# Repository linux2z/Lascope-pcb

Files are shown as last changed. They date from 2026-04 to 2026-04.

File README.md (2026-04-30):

# <div align="center">🧬 Lascope Hardware Ecosystem</div>

<div align="center">
  
  
  
</div>

<br />

<div align="center">
  <p><b>High-performance, hardware-accelerated imaging platform for next-generation endoscopy.</b></p>
  <i>Precision-engineered PCB designs for medical-grade reliability and low-latency throughput.</i>
</div>

---

## 📸 Hardware Overview: CM3588 Plus
The core of the Lascope system is the **FriendlyElec CM3588 Plus**, a high-performance SoM (System on Module) powered by the Rockchip RK3588.

<div align="center">
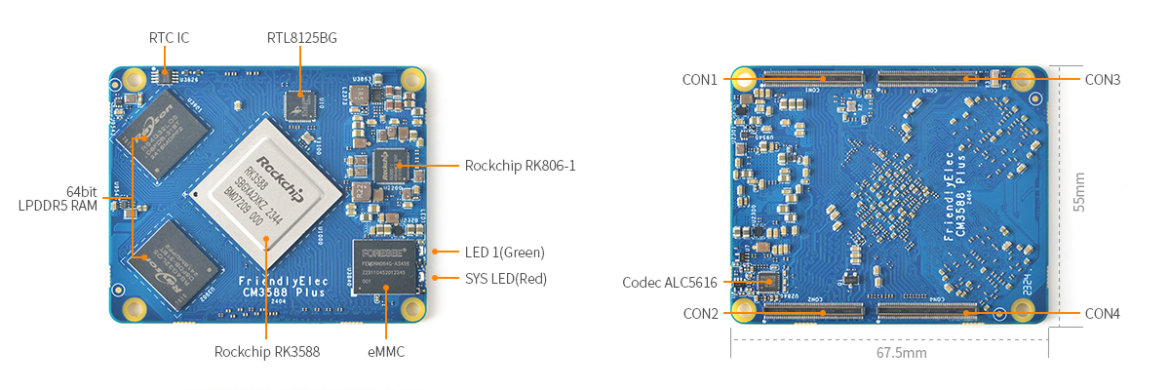
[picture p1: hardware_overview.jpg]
CM3588 Plus Hardware Layout
  
  <br />
  <i>Fig 1.0: CM3588 Plus Component Mapping (RK3588, LPDDR5 RAM, eMMC, and Peripherals)</i>
</div>

---

## 💎 Design Philosophy
The Lascope hardware architecture is built on a **Modular Sub-PCB Model**. By separating the high-speed computing core from the user interface and illumination modules, we ensure:
- **EMC Isolation:** High-speed signals are isolated on the Main Board (Board 1).
- **Serviceability:** Individual modules (Buttons, LEDs, Battery) can be replaced or upgraded independently.
- **Thermal Efficiency:** Optimized heat dissipation paths for the RK3588 SoC.

---

## 📂 Modular Deliverables

### 🖥️ Core Processing Unit
| Board ID | Name | Role | Specs |
| :--- | :--- | :--- | :--- |
| **BOARD 1** | **Main Controller** | System Logic & Vision | RK3588, 64-bit LPDDR5, Dual RTL8125BG |

### 💡 Illumination & Sensors
| Board ID | Name | Role | Key Specs |
| :--- | :--- | :--- | :--- |
| **BOARD 5** | **Camera LED** | Endoscopic Light Source | High-CRI 5700K LEDs |
| **BOARD 6** | **LED Controller** | PWM Dimming Logic | TLC59108 I2C Driver |

### 🔋 Power & Control
| Board ID | Name | Role | Key Specs |
| :--- | :--- | :--- | :--- |
| **BOARD 4** | **Battery BMS** | Power Management | Smart Charging & Fuel Gauge |
| **BOARD 2** | **Button Sub-PCB** | Tactile Interface | 5-Way Navigation Switch |
| **BOARD 3** | **Status Panel** | Visual Feedback | 5-LED Diagnostic Array |
| **BOARD 7** | **Power Logic** | Soft-Start Circuitry | Latching Power Switch |

---

## 🛠️ Production Standards

| Attribute | Specification |
| :--- | :--- |
| **PCB Stackup** | 8-Layer High-Density (Main) / 2-Layer (Sub) |
| **Material** | Isola 370HR / IT-180A (High TG) |
| **Surface Finish** | Lead-Free ENIG (Au: 0.05um, Ni: 3um) |
| **Impedance** | 90Ω Differential (USB), 100Ω (Ethernet) |
| **Certification** | IPC-A-600 Class 2 Compliance |

---

## 📥 Getting Started with Fabrication
1. **Gerber Review:** Open the `.zip` files in each directory using a CAM tool (e.g., CAM350 or Gerbv).
2. **SMT Assembly:** Provide the `PickAndPlace` and `BOM` files to your PCBA partner.
3. **Mechanical Fit:** Use the provided `.step` models to verify enclosure clearances before milling.

---

<div align="center">
  <sub>Proprietary and Confidential | &copy; 2026 Lascope Medical Imaging Systems</sub>
</div>

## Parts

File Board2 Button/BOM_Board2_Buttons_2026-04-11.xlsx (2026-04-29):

No. | Quantity | Comment | Designator | Footprint | Value | Manufacturer Part | Manufacturer | Supplier Part | Supplier
1 | 5 | 100nF | C57,C58,C59,C60,C61 | C0603 | 100nF | DT063X7R104KNTD | XINNA(新纳) | C41398818 | LCSC
2 | 1 | BM28B0.6-10DP/2-0.35V(51) | CN8 | CONN-SMD_BM28B0.6-10DP-2-0.35V-51 |  | BM28B0.6-10DP/2-0.35V(51) | HRS(广濑) | C424562 | LCSC
3 | 5 | G4R152312 | SW10,SW11,SW12,SW13,SW14 | SW-SMD_4P-L5.2-W5.2-P3.70-LS6.4_UK-B0233XX |  | G4R152312 | SAMZO(三佐) | C49393646 | LCSC

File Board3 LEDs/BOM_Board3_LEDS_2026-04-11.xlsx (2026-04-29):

No. | Quantity | Comment | Designator | Footprint | Value | Manufacturer Part | Manufacturer | Supplier Part | Supplier
1 | 1 | BM28B0.6-10DP/2-0.35V(51) | CN9 | CONN-SMD_BM28B0.6-10DP-2-0.35V-51 |  | BM28B0.6-10DP/2-0.35V(51) | HRS(广濑) | C424562 | LCSC
2 | 5 | KT-0603R | LED1,LED2,LED3,LED4,LED5 | LED0603-RD |  | KT-0603R | KENTO | C2286 | LCSC
3 | 5 | 100Ω | R1,R2,R3,R4,R5 | R0603 | 100Ω | 0603WAF1000T5E | UNI-ROYAL(厚声) | C22775 | LCSC

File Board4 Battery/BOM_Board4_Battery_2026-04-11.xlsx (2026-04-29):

No. | Quantity | Comment | Designator | Footprint | Value | Manufacturer Part | Manufacturer | Supplier Part | Supplier
1 | 1 | 1uF | C1 | C0603 | 1uF | CL10A105KB8NNNC | SAMSUNG(三星) | C15849 | LCSC
2 | 1 | A1257WR-S-2P | CN1 | CONN-SMD_A1257WR-S-2P |  | A1257WR-S-2P | CJT(长江连接器) | C225125 | LCSC
3 | 1 | DC-005 2.0 | DC3 | DC-IN-TH_DC-5520-1 |  | DC-005 2.0 | BOOMELE(博穆精密) | C16214 | LCSC
4 | 1 | MHT192WDT-CYAN | LED1 | LED0603-R-RD |  | MHT192WDT-CYAN | MEIHUA(美华科技) | C496821 | LCSC
5 | 1 | XL-1608UGC-04 | LED2 | LED0603-RD_GREEN |  | XL-1608UGC-04 | XINGLIGHT(成兴光) | C965804 | LCSC
6 | 2 | AO3401A | Q1,Q2 | SOT-23_L2.9-W1.3-P1.90-LS2.4-BR |  | AO3401A | UMW(广东友台半导体) | C347476 | LCSC
7 | 1 | 1kΩ | R1 | R0603 | 1kΩ | 0603WAF1001T5E | UNI-ROYAL(厚声) | C21190 | LCSC
8 | 4 | 10kΩ | R2,R4,R5,R6 | R0603 | 10kΩ | 0603WAF1002T5E | UNI-ROYAL(厚声) | C25804 | LCSC
9 | 2 | 47kΩ | R3,R9 | R0603 | 47kΩ | 0603WAF4702T5E | UNI-ROYAL(厚声) | C25819 | LCSC
10 | 2 | 100kΩ | R7,R8 | R0603 | 100kΩ | 0603WAF1003T5E | UNI-ROYAL(厚声) | C25803 | LCSC
11 | 1 | KF1027B-03P-G00-ON-01B | SW1 | SW-SMD_6P-L8.6-W6.2-P2.54-LS9.9 |  | KF1027B-03P-G00-ON-01B | 凯峰 | C976365 | LCSC
12 | 2 | 调试焊盘 | TP1,TP2 | 调试焊盘
13 | 1 | CH224K | U2 | ESOP-10_L4.9-W3.9-P1.00-LS6.2-BL-EP |  | CH224K | WCH(南京沁恒) | C970725 | LCSC
14 | 1 | KH-TYPE-C-16P | USB1 | USB-C-SMD_KH-TYPE-C-16P |  | KH-TYPE-C-16P | kinghelm(金航标) | C709357 | LCSC

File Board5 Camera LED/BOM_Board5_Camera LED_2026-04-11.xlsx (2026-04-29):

No. | Quantity | Comment | Designator | Footprint | Value | Manufacturer Part | Manufacturer | Supplier Part | Supplier
1 | 1 | BM28B0.6-20DS/2-0.35V(51) | CN6 | CONN-SMD_BM28B0.6-20DS-2-0.35V-51 |  | BM28B0.6-20DS/2-0.35V(51) | HRS(广濑) | C424567 | LCSC
2 | 16 | SZYY0402W | LED1,LED2,LED3,LED4,LED5,LED6,LED7,LED8,LED9,LED10,LED11,LED12,LED13,LED14,LED15,LED16 | LED0402-RD_WHITE |  | SZYY0402W | yongyu(永裕光电) | C434448 | LCSC

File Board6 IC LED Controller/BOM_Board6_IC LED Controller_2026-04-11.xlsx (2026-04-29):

No. | Quantity | Comment | Designator | Footprint | Value | Manufacturer Part | Manufacturer | Supplier Part | Supplier
1 | 1 | BM28B0.6-20DP/2-0.35V(51) | CN6 | CONN-SMD_BM28B0.6-20DP-2-0.35V-51 |  | BM28B0.6-20DP/2-0.35V(51) | HRS(广濑) | C424566 | LCSC
2 | 1 | BM28B0.6-10DP/2-0.35V(51) | CN7 | CONN-SMD_BM28B0.6-10DP-2-0.35V-51 |  | BM28B0.6-10DP/2-0.35V(51) | HRS(广濑) | C424562 | LCSC
3 | 4 | 2.2kΩ | R9,R10,R11,R12 | R0603 | 2.2kΩ | 0603WAF2201T5E | UNI-ROYAL(厚声) | C4190 | LCSC
4 | 2 | 10kΩ | R13,R14 | R0603 | 10kΩ | 0603WAF1002T5E | UNI-ROYAL(厚声) | C25804 | LCSC
5 | 2 | 9.1kΩ | R15,R16 | R0603 | 9.1kΩ | 0603WAF9101T5E | UNI-ROYAL(厚声) | C23260 | LCSC
6 | 2 | TLC59108IRGYR | U2,U3 | VQFN-20_L4.5-W3.5-P0.50-BL-EP-1 |  | TLC59108IRGYR | TI(德州仪器) | C201600 | LCSC

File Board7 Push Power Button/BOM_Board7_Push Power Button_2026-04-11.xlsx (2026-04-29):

No. | Quantity | Comment | Designator | Footprint | Value | Manufacturer Part | Manufacturer | Supplier Part | Supplier
1 | 1 | A1257WR-S-2P | CN1 | CONN-SMD_A1257WR-S-2P |  | A1257WR-S-2P | CJT(长江连接器) | C225125 | LCSC
2 | 1 | K8-5851E-N1 | SW1 | SW-TH_6P-L5.8-W5.8-P2.00-LS4.5-BR |  | K8-5851E-N1 | 韩国韩荣 | C134191 | LCSC

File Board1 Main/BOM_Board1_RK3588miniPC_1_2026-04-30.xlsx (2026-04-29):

No. | Quantity | Comment | Designator | Footprint | Value | Manufacturer Part | Manufacturer | Supplier Part | Supplier
1 | 4 | BM28B0.6-10DS/2-0.35V(51) | Buttons,CN9,Illumi_Led,LEDS | CONN-SMD_BM28B0.6-10DS-2-0.35V-51 |  | BM28B0.6-10DS/2-0.35V(51) | HRS(广濑) | C424563 | LCSC
2 | 1 | 3kHz | BUZZER1 | BUZ-SMD_L9.6-W9.6-LS10.0-R | 3kHz | FUET-9650B-3V | FUET(福声科技) | C391032 | LCSC
3 | 27 | 10uF | C1,C2,C4,C8,C9,C10,C11,C12,C13,C19,C20,C21,C22,C23,C24,C25,C26,C27,C31,C32,C46,C47,C49,C50,C52,C53,C55 | C0805 | 10uF | CL21A106KAYNNNE | SAMSUNG(三星) | C15850 | LCSC
4 | 8 | 100nF | C3,C5,C16,C28,C48,C51,C54,C56 | C0402 | 100nF | CC0402KRX7R7BB104 | YAGEO(国巨) | C60474 | LCSC
5 | 7 | 1uF | C6,C15,C17,C33,C34,C35,C37 | C0402 | 1uF | CL05A105KP5NNNC | SAMSUNG(三星) | C14445 | LCSC
6 | 2 | 22pF | C7,C18 | C0402 | 22pF | 0402CG220J500NT | FH(风华) | C1555 | LCSC
7 | 2 | 220pF | C29,C30 | C0402 | 220pF | 0402B221K500NT | FH(风华) | C1530 | LCSC
8 | 1 | 100pF | C36 | C0402 | 100pF | 0402CG101J500NT | FH(风华) | C1546 | LCSC
9 | 4 | 1nF | C39,C40,C43,C44 | C0402 | 1nF | CC0402KRX7R9BB102 | YAGEO(国巨) | C106205 | LCSC
10 | 1 | TF-115-BCP9 | CARD1 | TF-SMD_TF-115-BCP9 |  | TF-115-BCP9 | XUNPU(讯普) | C720505 | LCSC
11 | 1 | A2012WVA-3P | CN2 | CONN-TH_A2012WVA-3P |  | A2012WVA-3P | CJT(长江连接器) | C225375 | LCSC
12 | 4 | DF40HC(3.0)-100DS-0.4V(51) | CN3,CN4,CN5,CN6 | CONN-SMD_DF40HC-3.0-100DS-0.4V-51 |  | DF40HC(3.0)-100DS-0.4V(51) | HRS(广濑) | C424649 | LCSC
13 | 2 | A1257WR-S-2P | CN10,CN10 | CONN-SMD_A1257WR-S-2P |  | A1257WR-S-2P | CJT(长江连接器) | C225125 | LCSC
14 | 1 | SMAJ15A | D1 | SMA_L4.3-W2.6-LS5.1-RD |  | SMAJ15A | GOODWORK(固得沃克) | C908769 | LCSC
15 | 2 | LRB521S-30T1G | D2,D7 | SOD-523_L1.2-W0.8-LS1.6-RD |  | LRB521S-30T1G | LRC(乐山无线电) | C83681 | LCSC
16 | 9 | LESD8D5.0CAT5G | D3,D8,D9,D10,D11,D12,D19,D20,D24 | SOD-882_L1.0-W0.6-BI |  | LESD8D5.0CAT5G | LRC(乐山无线电) | C172411 | LCSC
17 | 9 | AZ1045-04F | D4,D5,D6,D21,D22,D23,D25,D26,D27 | DFN2510-10_L2.5-W1.0-P0.50-BL |  | AZ1045-04F | TECH PUBLIC(台舟) | C2987152 | LCSC
18 | 2 | ESD73034D-10/TR | D13,D14 | DFN2510-10_L2.5-W1.0-P0.50-BL |  | ESD73034D-10/TR | WILLSEMI(韦尔) | C2941834 | LCSC
19 | 1 | DC-005-A250 | DC1 | DC-IN-TH_DC-005-A250 |  | DC-005-A250 | XUNPU(讯普) | C720558 | LCSC
20 | 1 | ZH1.5-2P-LT | FAN1 | CONN-SMD_ZH1.5-2P-LT |  | ZH1.5-2P-LT | CAX(创都) | C722912 | LCSC
21 | 1 | USB-303WSD-BRY | J1 | USB-A-TH_XUNPU_USB-303WSD-BRY |  | USB-303WSD-BRY | XUNPU(讯普) | C2895028 | LCSC
22 | 1 | 3.3uH | L1 | IND-SMD_L7.0-W6.6 | 3.3uH | MWSA0603S-3R3MT | Sunlord(顺络) | C408446 | LCSC
23 | 1 | 2.2uH | L2 | IND-SMD_L4.0-W4.0 | 2.2uH | WPN4020H2R2MT | Sunlord(顺络) | C98361 | LCSC
24 | 1 | BS-2AG13-9 | P1 | BS-2AG13-9
25 | 3 | AO3415A | Q1,Q2,Q3 | SOT-23-3_L3.0-W1.7-P0.95-LS2.9-BR |  | AO3415A | UMW(友台半导体) | C347479 | LCSC
26 | 4 | WNM6002-3/TR | Q4,Q5,Q6,Q7 | SOT-323-3_L2.0-W1.3-P1.30-LS2.1-BR |  | WNM6002-3/TR | WILLSEMI(韦尔) | C501342 | LCSC
27 | 1 | SS8050(RANGE:200-350) | Q8 | SOT-23-3_L2.9-W1.3-P1.90-LS2.4-BR |  | SS8050(RANGE:200-350) | CJ(江苏长电/长晶) | C2150 | LCSC
28 | 10 | 10kΩ | R1,R2,R4,R9,R13,R17,R22,R27,R32,R33 | R0402 | 10kΩ | RC-02W1002FT | FH(风华) | C258091 | LCSC
29 | 1 | 20kΩ | R3 | R0402 | 20kΩ | RC-02W2002FT | FH(风华) | C258096 | LCSC
30 | 1 | 56kΩ | R5 | R0402 | 56kΩ | 0402WGF5602TCE | UNI-ROYAL(厚声) | C25796 | LCSC
31 | 2 | 10kΩ | R6,R11 | R0402 | 10kΩ | RC0402FR-0710KL | YAGEO(国巨) | C60490 | LCSC
32 | 5 | 100kΩ | R7,R21,R59,R61,R63 | R0402 | 100kΩ | RC0402FR-07100KL | YAGEO(国巨) | C60491 | LCSC
33 | 1 | 150kΩ | R8 | R0402 | 150kΩ | 0402WGF1503TCE | UNI-ROYAL(厚声) | C25755 | LCSC
34 | 1 | 33.2kΩ | R10 | R0402 | 33.2kΩ | RC0402FR-0733K2L | YAGEO(国巨) | C130276 | LCSC
35 | 1 | 2.2Ω | R12 | R0402 | 2.2Ω | 0402WGF220KTCE | UNI-ROYAL(厚声) | C25101 | LCSC
36 | 1 | 470Ω | R14 | R0402 | 470Ω | 0402WGF4700TCE | UNI-ROYAL(厚声) | C25117 | LCSC
37 | 20 | 33Ω | R15,R64,R65,R66,R67,R68,R69,R70,R71,R72,R73,R74,R75,R76,R77,R78,R79,R80,R81,R82 | R0402 | 33Ω | 0402WGF330JTCE | UNI-ROYAL(厚声) | C25105 | LCSC
38 | 2 | 1kΩ | R16,R25 | R0402 | 1kΩ | 0402WGF1001TCE | UNI-ROYAL(厚声) | C11702 | LCSC
39 | 5 | 100Ω | R18,R41,R47,R49,R53 | R0402 | 100Ω | 0402WGF1000TCE | UNI-ROYAL(厚声) | C25076 | LCSC
40 | 1 | 0Ω | R19 | R0402 | 0Ω | 0402WGF0000TCE | UNI-ROYAL(厚声) | C17168 | LCSC
41 | 4 | 4.7kΩ | R20,R58,R60,R62 | R0402 | 4.7kΩ | 0402WGF4701TCE | UNI-ROYAL(厚声) | C25900 | LCSC
42 | 3 | 1.8kΩ | R23,R26,R34 | R0402 | 1.8kΩ | 0402WGF1801TCE | UNI-ROYAL(厚声) | C25871 | LCSC
43 | 1 | 27kΩ | R24 | R0402 | 27kΩ | 0402WGF2702TCE | UNI-ROYAL(厚声) | C25771 | LCSC
44 | 8 | 499Ω | R28,R29,R30,R31,R35,R36,R37,R38 | R0402 | 499Ω | 0402WGF4990TCE | UNI-ROYAL(厚声) | C4125 | LCSC
45 | 1 | 47kΩ | R39 | R0402 | 47kΩ | 0402WGF4702TCE | UNI-ROYAL(厚声) | C25792 | LCSC
46 | 1 | 2.2kΩ | R83 | R0603 | 2.2kΩ | 0603WAF2201T5E | UNI-ROYAL(厚声) | C4190 | LCSC
47 | 1 | 10kΩ | R84 | R0603 | 10kΩ | 0603WAF1002T5E | UNI-ROYAL(厚声) | C25804 | LCSC
48 | 2 | 0Ω | RN1,RN2 | RES-ARRAY-SMD_0402-8P-L2.0-W1.0-BL | 0Ω | RC-MT08W000JT | FH(风华) | C2001 | LCSC
49 | 4 | 0Ω | RN5,RN6,RN7,RN8 | RES-ARRAY-SMD_0402-4P-L1.0-W1.0-BL | 0Ω | 2D02WGJ0000TCE | UNI-ROYAL(厚声) | C75375 | LCSC
50 | 4 | TS-1092S-B3D2-G | SW1,SW2,SW3,SW4 | SW-SMD_L6.1-W3.6-LS7.9 |  | TS-1092S-B3D2-G | Yuandi(元迪) | C520860 | LCSC
51 | 2 | TPS564201DDCR | U1,U3 | SOT-23-6_L2.9-W1.6-P0.95-LS2.8-BL |  | TPS564201DDCR | TI(德州仪器) | C464812 | LCSC
52 | 1 | RT9193-18GB | U2 | SOT-23-5_L3.0-W1.7-P0.95-LS2.8-BR |  | RT9193-18GB | RICHTEK(立锜) | C27416 | LCSC
53 | 6 | 2SK3018W | U4,U7,U8,U9,U11,U12 | SOT-323_L2.1-W1.3-P0.65-LS2.3-BR |  | 2SK3018W | TWGMC(台湾迪嘉) | C5273793 | LCSC
54 | 4 | SY6280AAC | U5,U14,U15,U16 | SOT-23-5_L3.0-W1.7-P0.95-LS2.8-BL |  | SY6280AAC | silergy(矽力杰) | C55136 | LCSC
55 | 1 | Fusb302mpx | U6 | MLP-14_L2.5-W2.5-P0.50-BL-EP |  | Fusb302mpx | onsemi(安森美) | C442699 | LCSC
56 | 1 | AP2331W-7 | U10 | SC-59-3_L2.9-W1.5-P0.95-LS2.5-BR |  | AP2331W-7 | DIODES(美台) | C460346 | LCSC
57 | 1 | U221-041N-1WR69-S1 | U17 | USB-A-TH_U221-041N-1WR69-S-5 |  | U221-041N-1WR69-S1 | HanElectricity(瀚源) | C7471822 | LCSC
58 | 1 | HDMI-001S | USB2 | HDMI-SMD_HDMI-001S |  | HDMI-001S | XUNPU(讯普) | C720616 | LCSC
59 | 1 | TYPE-C 24P QT | USB4 | USB-C-SMD_TYPE-C-24P-QT |  | TYPE-C 24P QT | SHOU HAN(首韩) | C2681555 | LCSC

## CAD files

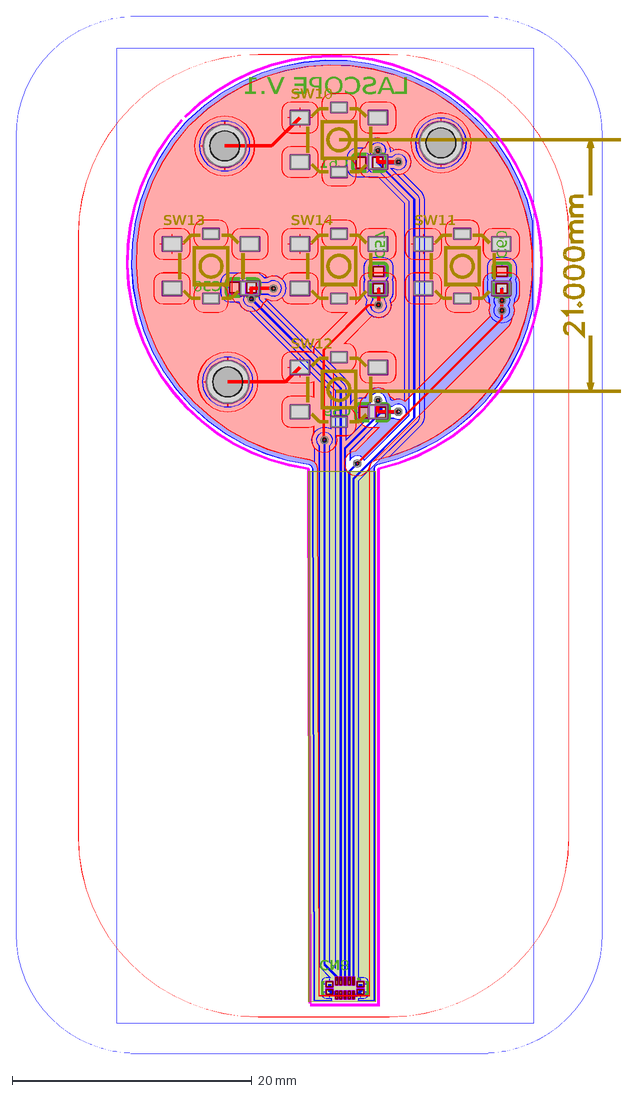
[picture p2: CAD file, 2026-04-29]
Board2 Button/DXF_Buttons_2026-04-11_AutoCAD2007.dxf
LASCOPE V.1
C57
C58
C59
C60
C61
CN8
SW10
SW12
SW13
SW14
SW11

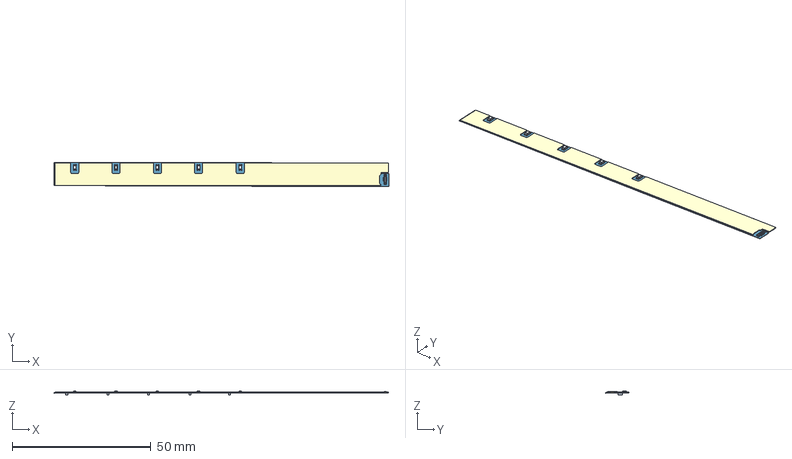
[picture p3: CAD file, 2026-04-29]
Board3 LEDs/3D_LEDS_2026-04-11.step
120.6 x 8.48 x 1.59 mm
Board~TwmB
TopCopper~TwmB
BottomCopper~TwmB
TopFpcStiffener~TwmB
BottomFpcStiffener~TwmB
CONN-SMD_BM28B0.6-10DP-2-0.35V-51~CONN-SMD_ BM28B0.6-10DP-2-0.35V-51~TwmB
R5~R0603~R0603~TwmB x 5
LED0603-RD~LED0603-RD~TwmB x 5

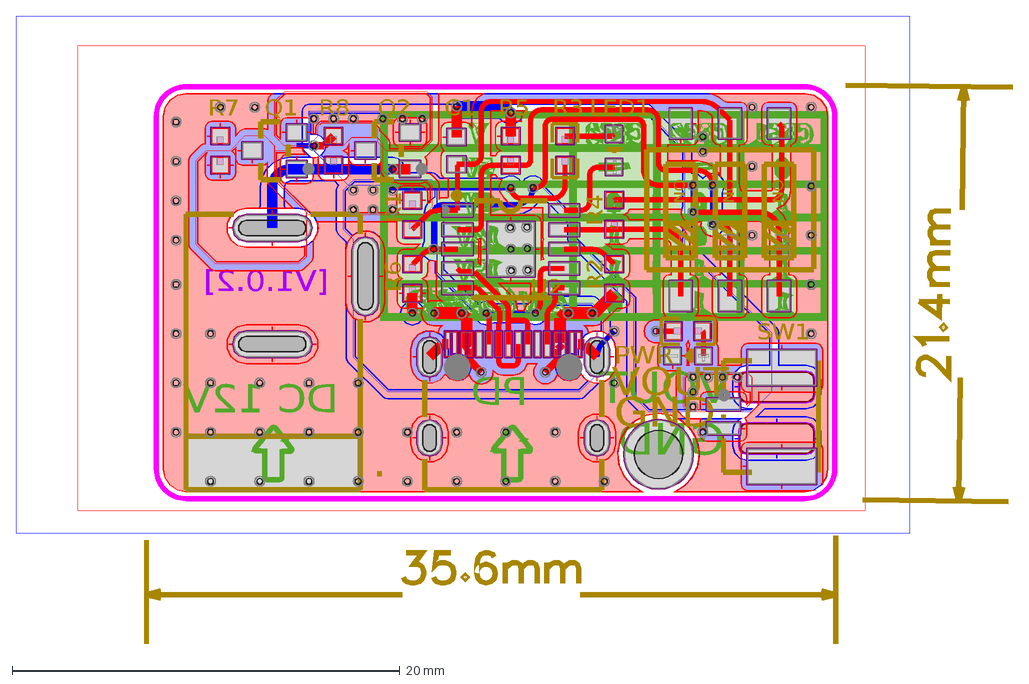
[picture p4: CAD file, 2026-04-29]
Board4 Battery/DXF_Battery_2026-04-11_AutoCAD2007.dxf
DC 12V
PD
VOUT
GND
[V1.0.2]
.
PWR
R7
Q1
R8
Q2
R1
R6
C1
U2
R5
R3
R2
R4
LED1
ON
SW1

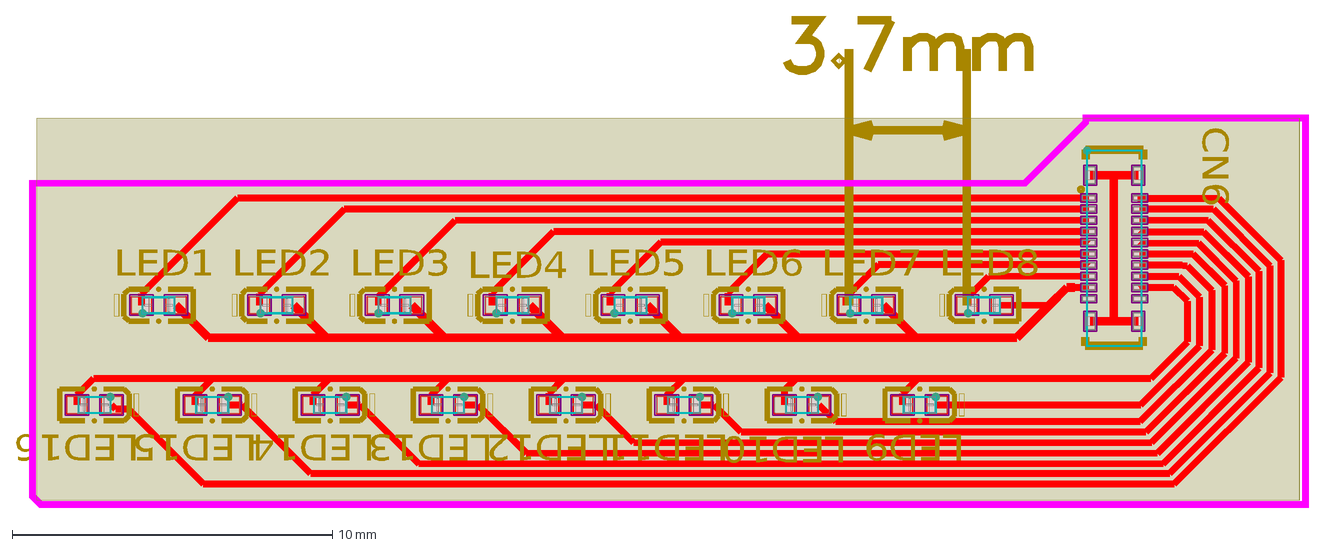
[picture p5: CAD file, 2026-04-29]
Board5 Camera LED/DXF_Camera LED_2026-04-11_AutoCAD2007.dxf
CN6
LED1
LED2
LED3
LED4
LED5
LED6
LED7
LED8
LED9
LED10
LED11
LED12
LED13
LED14
LED15
LED16

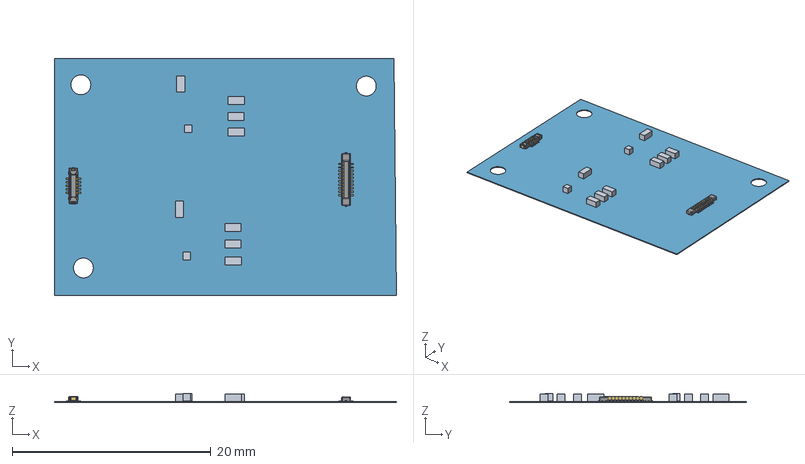
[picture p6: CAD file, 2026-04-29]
Board6 IC LED Controller/3D_IC LED Controller_2026-04-11.step
34.4 x 23.9 x 0.885 mm
Board~maNI
TopCopper~maNI
BottomCopper~maNI
TopFpcStiffener~maNI
BottomFpcStiffener~maNI
CONN-SMD_BM28B0.6-10DP-2-0.35V-51~CONN-SMD_ BM28B0.6-10DP-2-0.35V-51~maNI
R16~R0603~R0603~maNI x 8
U3~VQFN-20_L4.5-W3.5-P0.50-BL-EP-1~VQFN-20_L4.5-W3.5-H1.0-P0.50~maNI x 2
CONN-SMD_BM28B0.6-20DP-2-0.35V-51~CONN-SMD_ BM28B0.6-20DP-2-0.35V-51~maNI

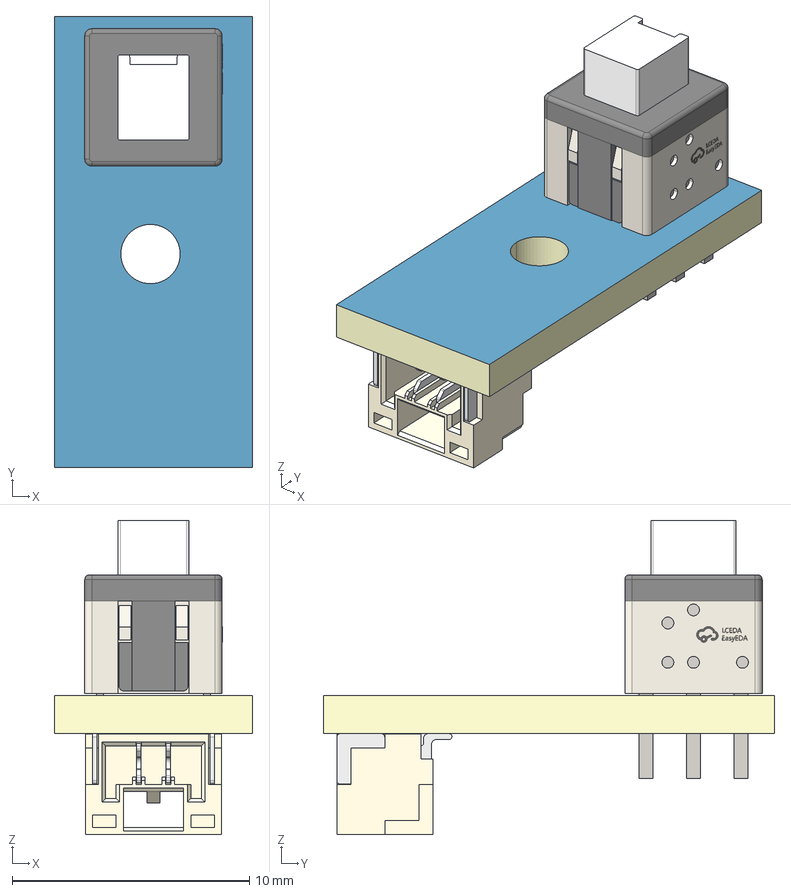
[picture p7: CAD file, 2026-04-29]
Board7 Push Power Button/3D_Push Power Button_2026-04-11.step
8.36 x 19.0 x 13.3 mm
Board~itif
TopCopper~itif
BottomCopper~itif
TopFpcStiffener~itif
BottomFpcStiffener~itif
CONN-SMD_A1257WR-S-2P~CONN-SMD_GH1.25-WS-2P~itif
SW-TH_6P-L5.8-W5.8-P2.00-LS4.5-BR~SW-TH_ 6P-L5.8-W5.8-P2.00-LS4.5-BR~itif

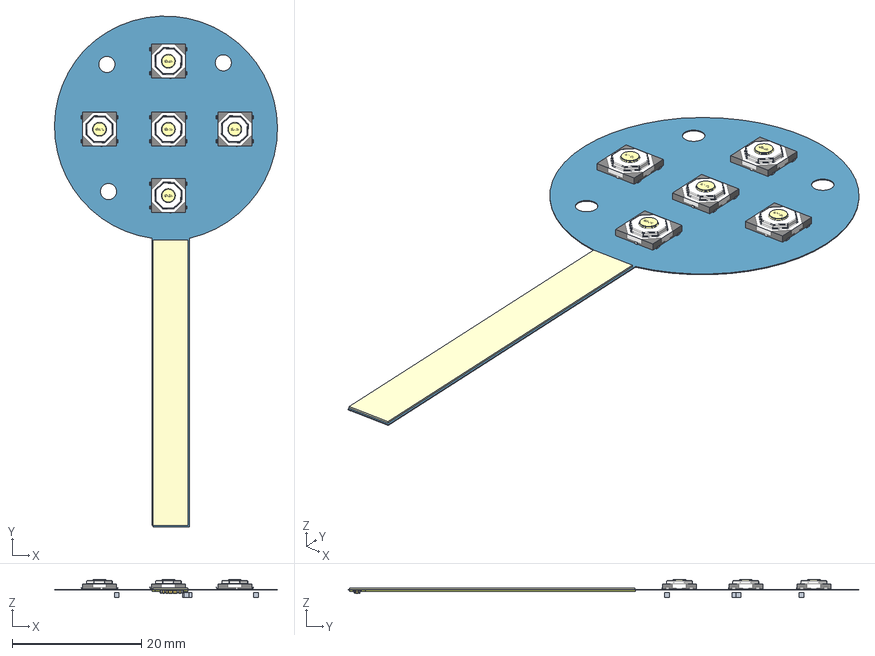
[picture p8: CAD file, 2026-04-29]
Board2 Button/3D_Buttons_2026-04-11.step
34.5 x 79.1 x 2.81 mm
Board~6mt2
TopCopper~6mt2
BottomCopper~6mt2
TopFpcStiffener~6mt2
BottomFpcStiffener~6mt2
C61~C0603~C0603_L1.6-W0.8-H0.8~6mt2 x 5
SW-SMD_4P-L5.2-W5.2-P3.70-LS6.4_UK-B0233XX~SW-SMD_ 4P-L5.2-W5.2-H1.5-P3.70-LS5.4_UK-B0232XX~6mt2 x 5
CONN-SMD_BM28B0.6-10DP-2-0.35V-51~CONN-SMD_ BM28B0.6-10DP-2-0.35V-51~6mt2

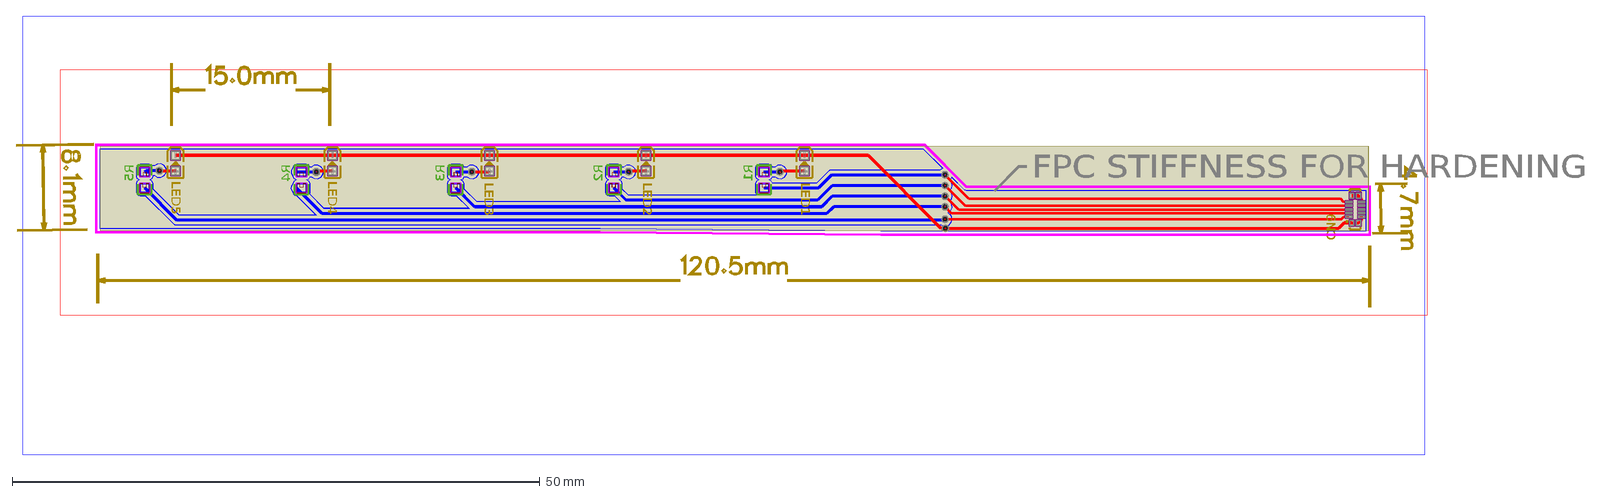
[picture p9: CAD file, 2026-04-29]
Board3 LEDs/DXF_LEDS_2026-04-11_AutoCAD2007.dxf
R1
R2
R3
R4
R5
LED1
LED2
LED3
LED4
LED5
CN9
FPC STIFFNESS FOR HARDENING

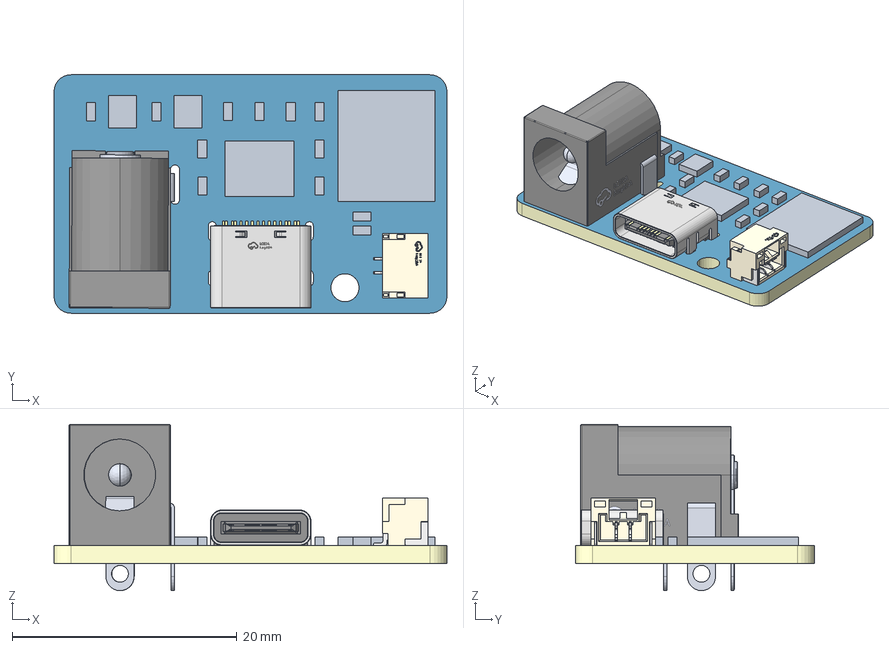
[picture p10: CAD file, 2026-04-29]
Board4 Battery/3D_Battery_2026-04-11.step
35.0 x 21.2 x 14.8 mm
Board~fnzt
TopCopper~fnzt
BottomCopper~fnzt
TopFpcStiffener~fnzt
BottomFpcStiffener~fnzt
LED0603-R-RD~LED0603-R-RD~fnzt
R9~R0603~R0603~fnzt x 5
DC-IN-TH_DC-5520-1~DC-IN-TH_DC-5520-1~fnzt
Q2~SOT-23_L2.9-W1.3-P1.90-LS2.4-BR~SOT-23-3P_ L2.9-W1.3-H1.0-LS2.4-P0.95~fnzt x 2
ESOP-10_L4.9-W3.9-P1.00-LS6.2-BL-EP~ESOP-10_ L4.9-W3.9-H1.4-P1.00-LS6.2-BL-EP~fnzt
R4~R0603~R0603_L1.6-W0.8-H0.8~fnzt x 4
SW-SMD_6P-L8.6-W6.2-P2.54-LS9.9~SW-SMD_6P-L8.6-W6.2-P2.54-LS9.9~fnzt
CONN-SMD_A1257WR-S-2P~CONN-SMD_GH1.25-WS-2P~fnzt
C0603~C0603_L1.6-W0.8-H0.8~fnzt
LED0603-RD_GREEN~LED0603-RD_GREEN~fnzt
USB-C-SMD_KH-TYPE-C-16P~USB-C-SMD_TYPE-C-31-M-12A~fnzt

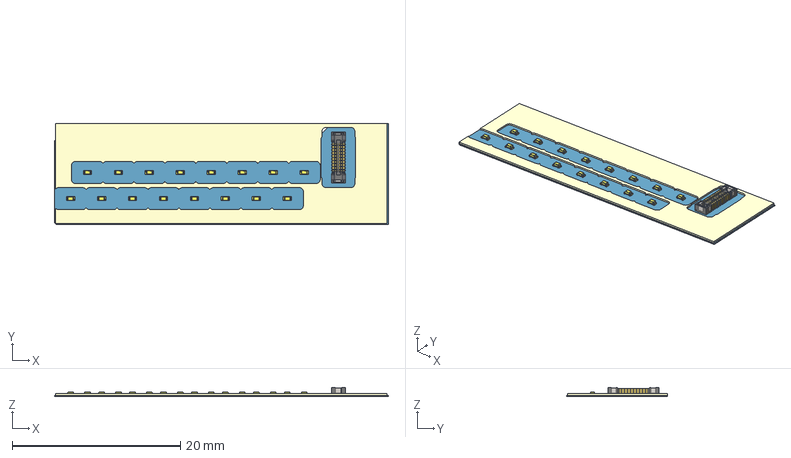
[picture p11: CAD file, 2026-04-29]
Board5 Camera LED/3D_Camera LED_2026-04-11.step
39.7 x 12.1 x 1.01 mm
Board~H0By
TopCopper~H0By
BottomCopper~H0By
TopFpcStiffener~H0By
BottomFpcStiffener~H0By
LED0402-RD_WHITE~LED0402-RD_WHITE~H0By x 16
CONN-SMD_BM28B0.6-20DS-2-0.35V-51~CONN-SMD_ BM28B0.6-20DS-2-0.35V-51~H0By

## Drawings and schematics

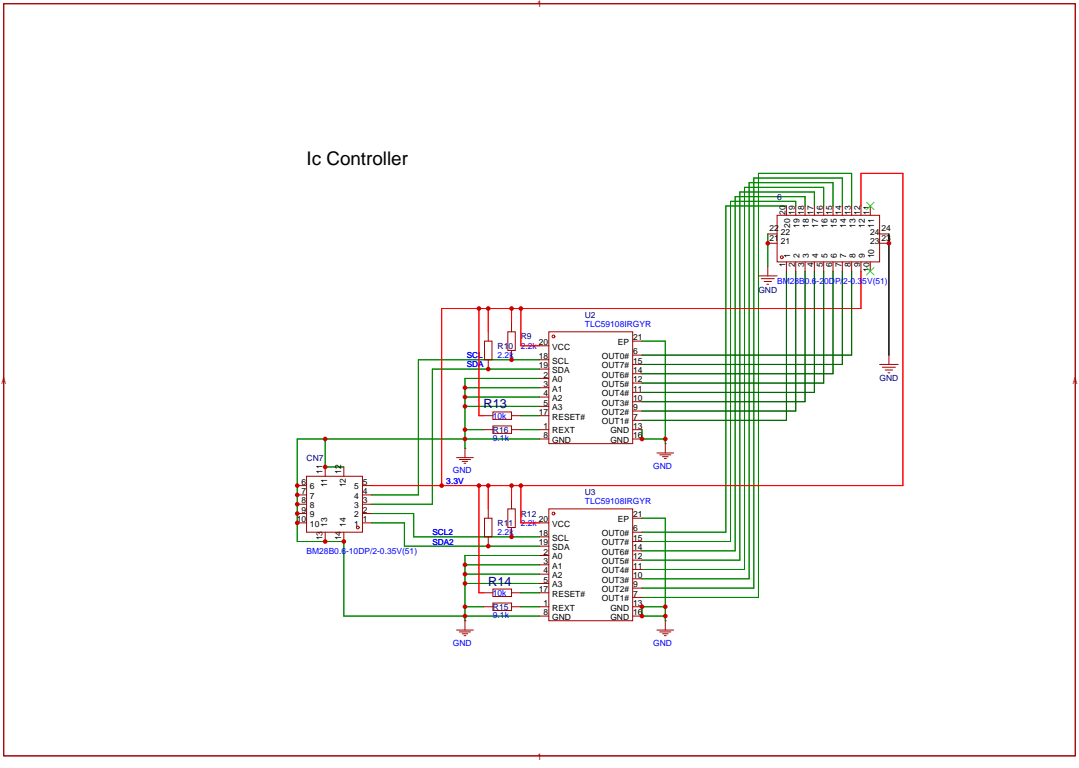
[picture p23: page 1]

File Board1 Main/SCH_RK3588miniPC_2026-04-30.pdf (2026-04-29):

# Power

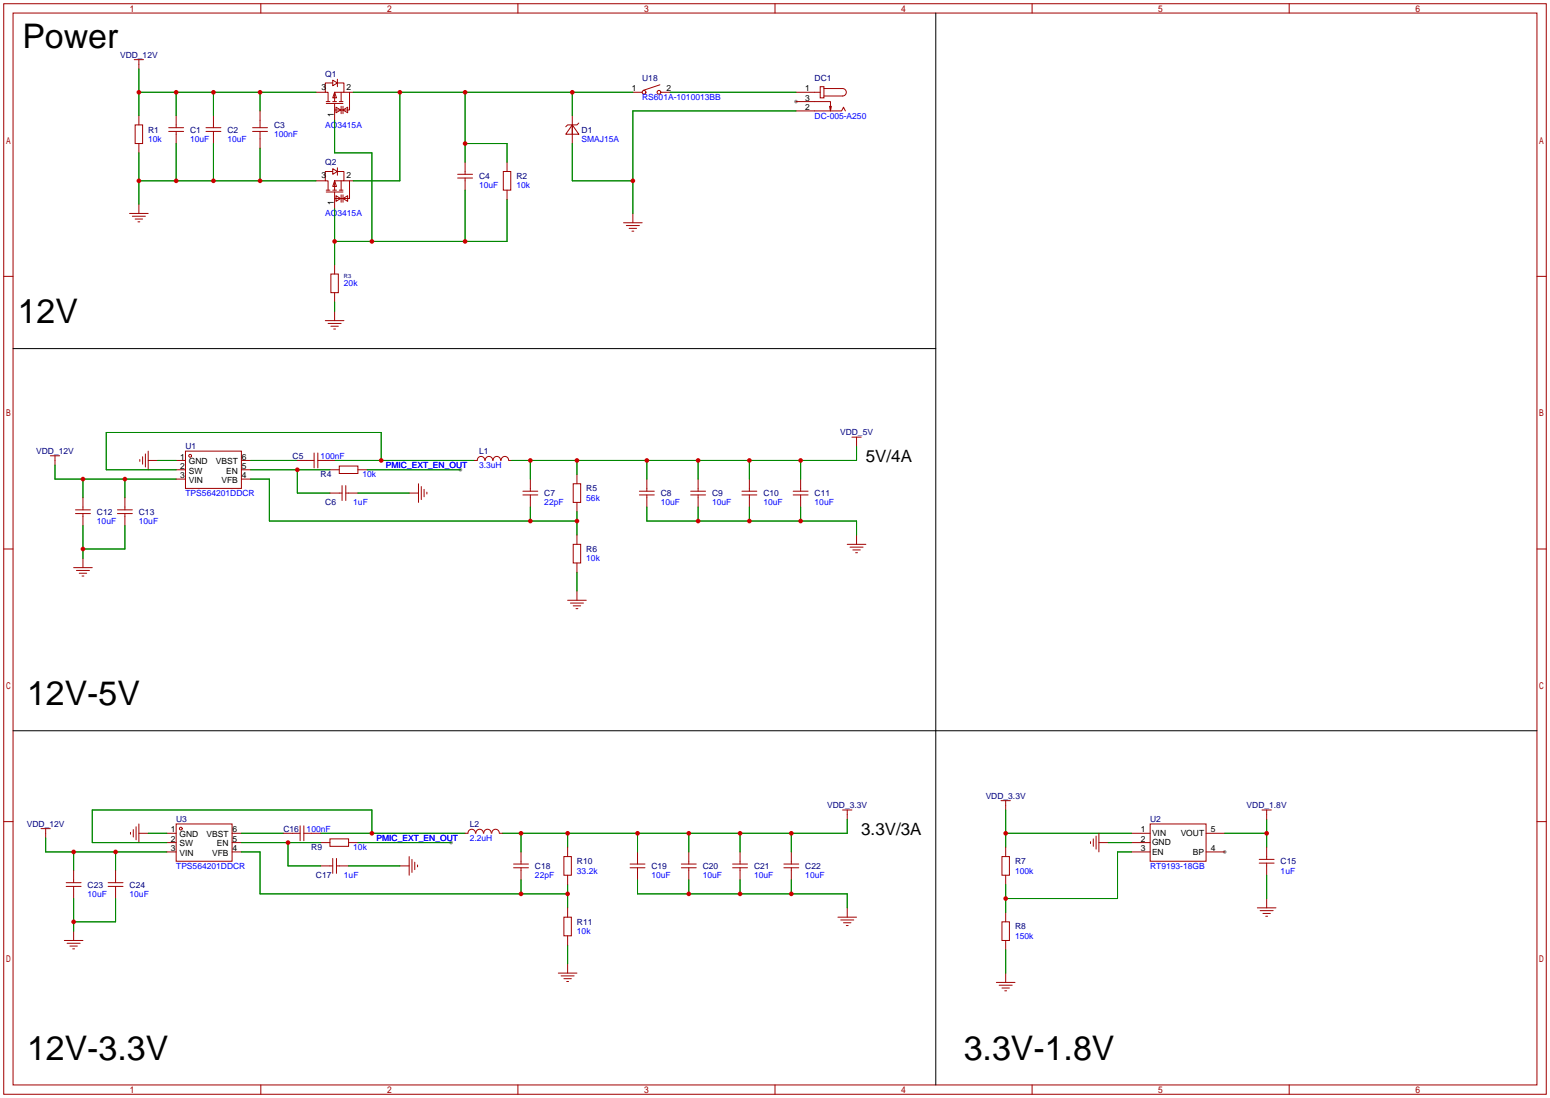
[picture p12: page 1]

RK3588miniPC | Fan

# Buzzer

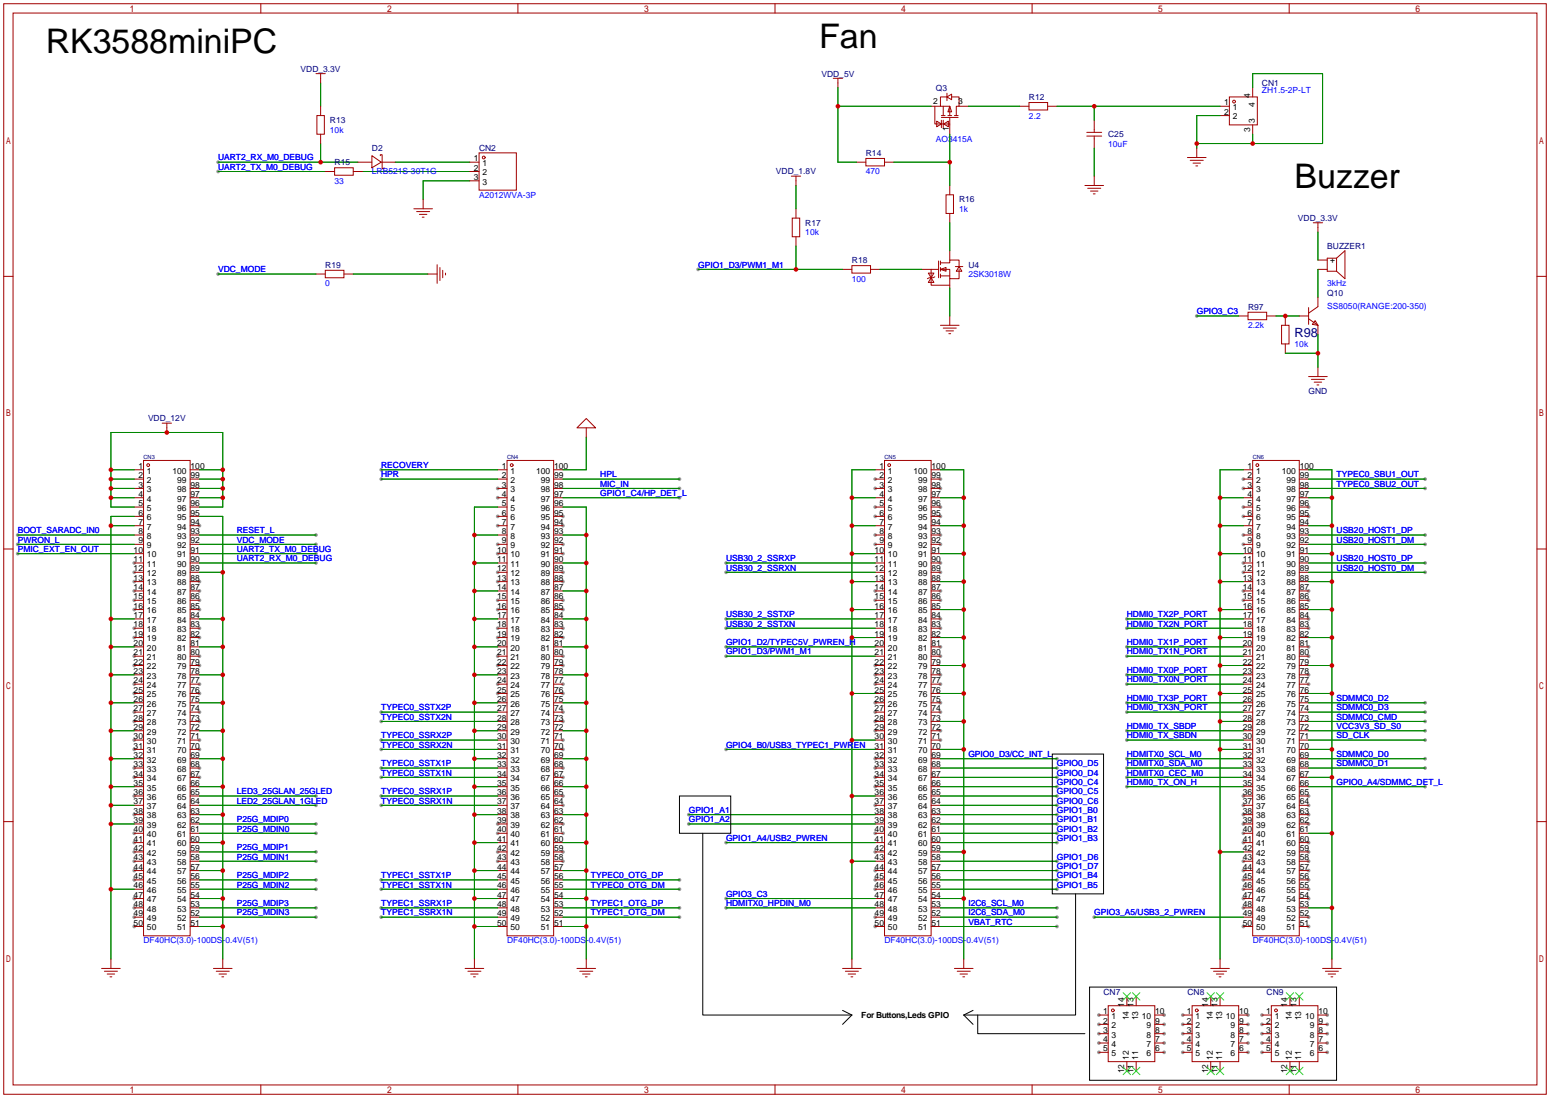
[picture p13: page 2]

# TypeC5V

# TypeC

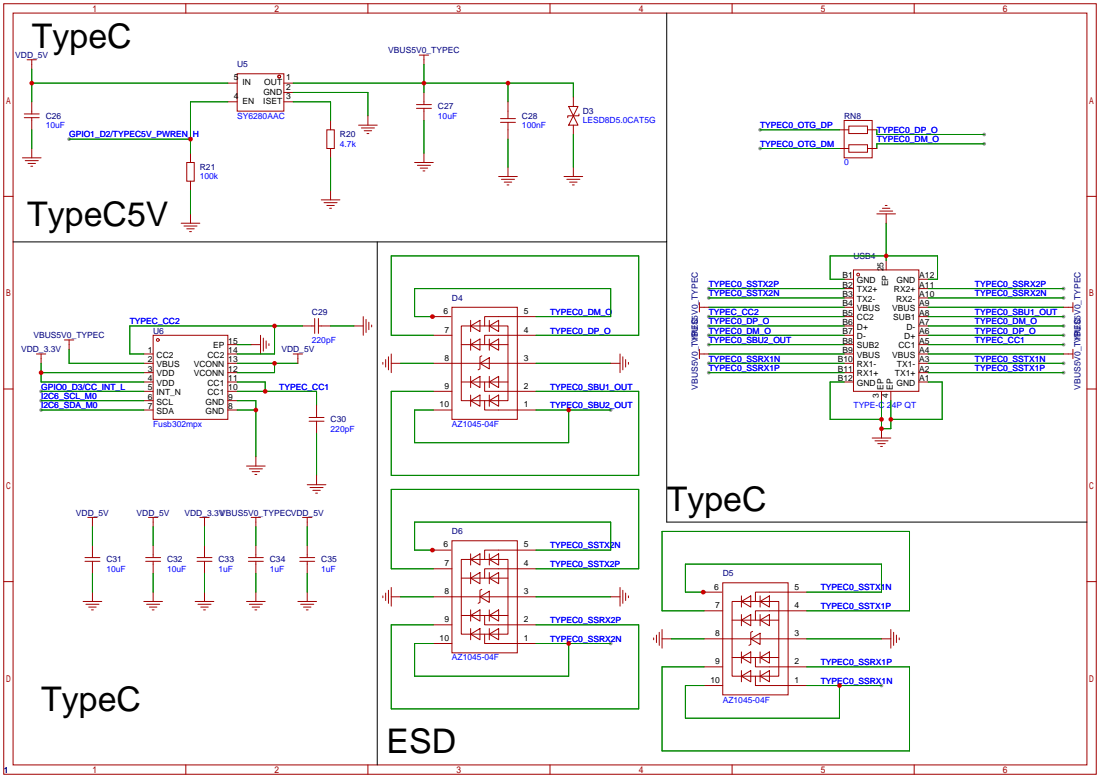
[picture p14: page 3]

# HDMI

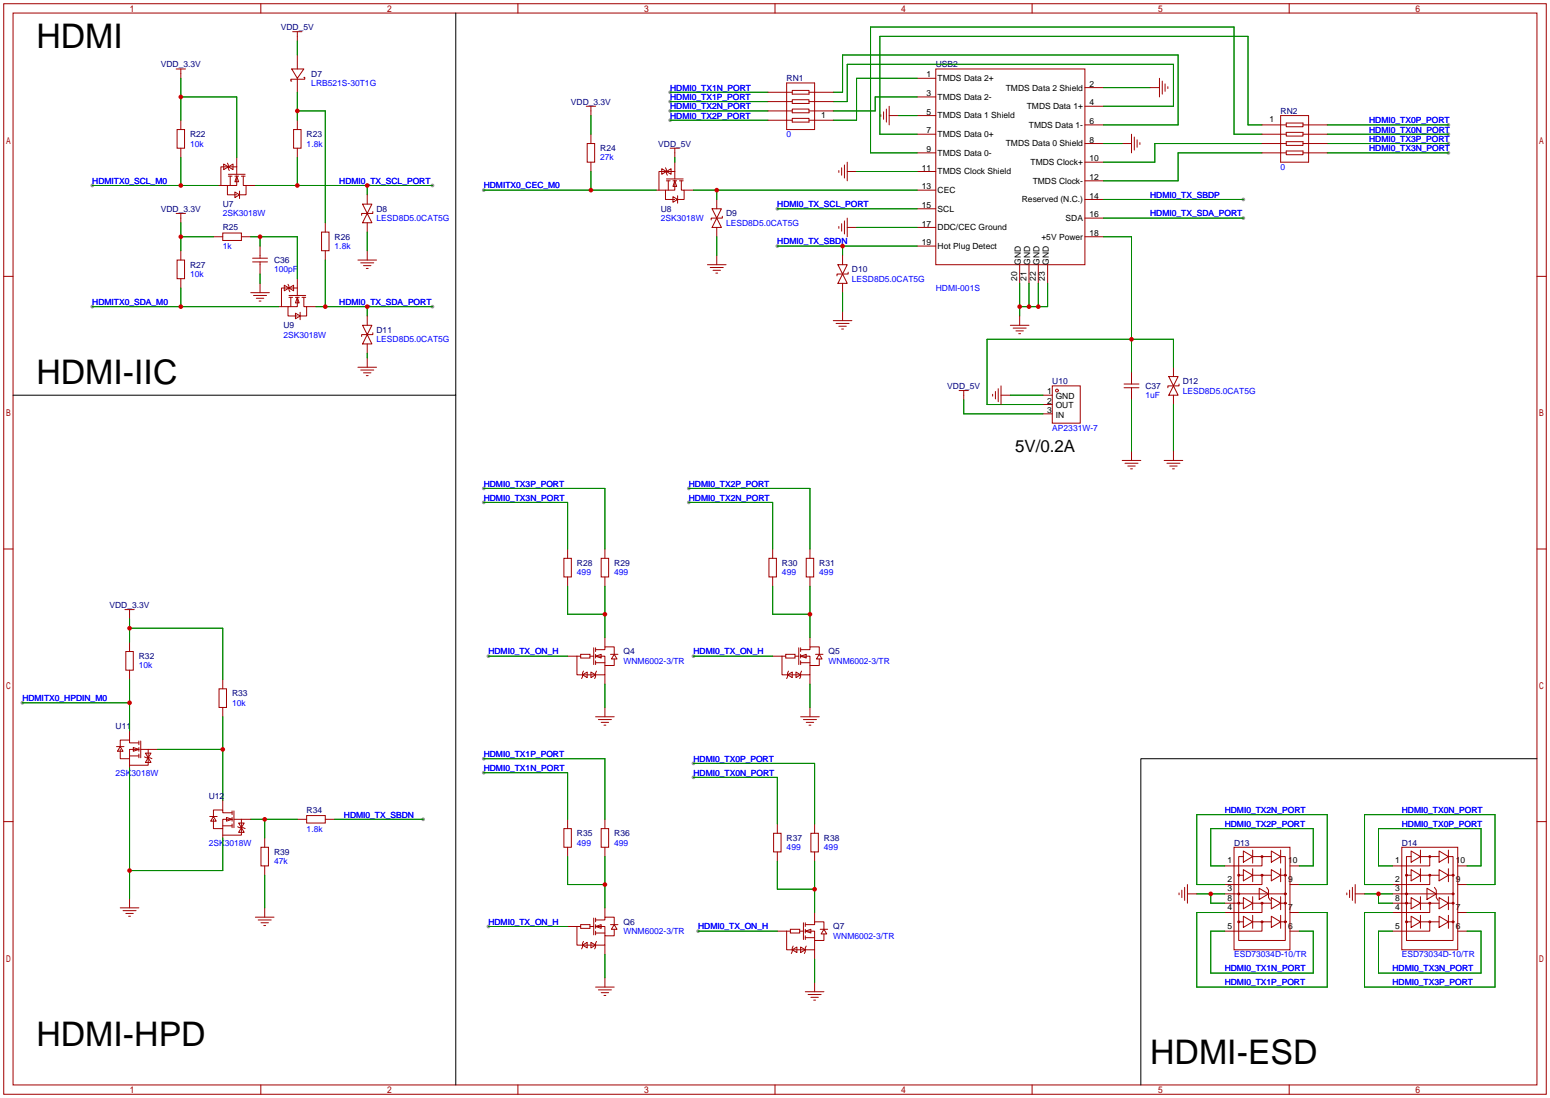
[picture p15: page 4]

# Battery-Button

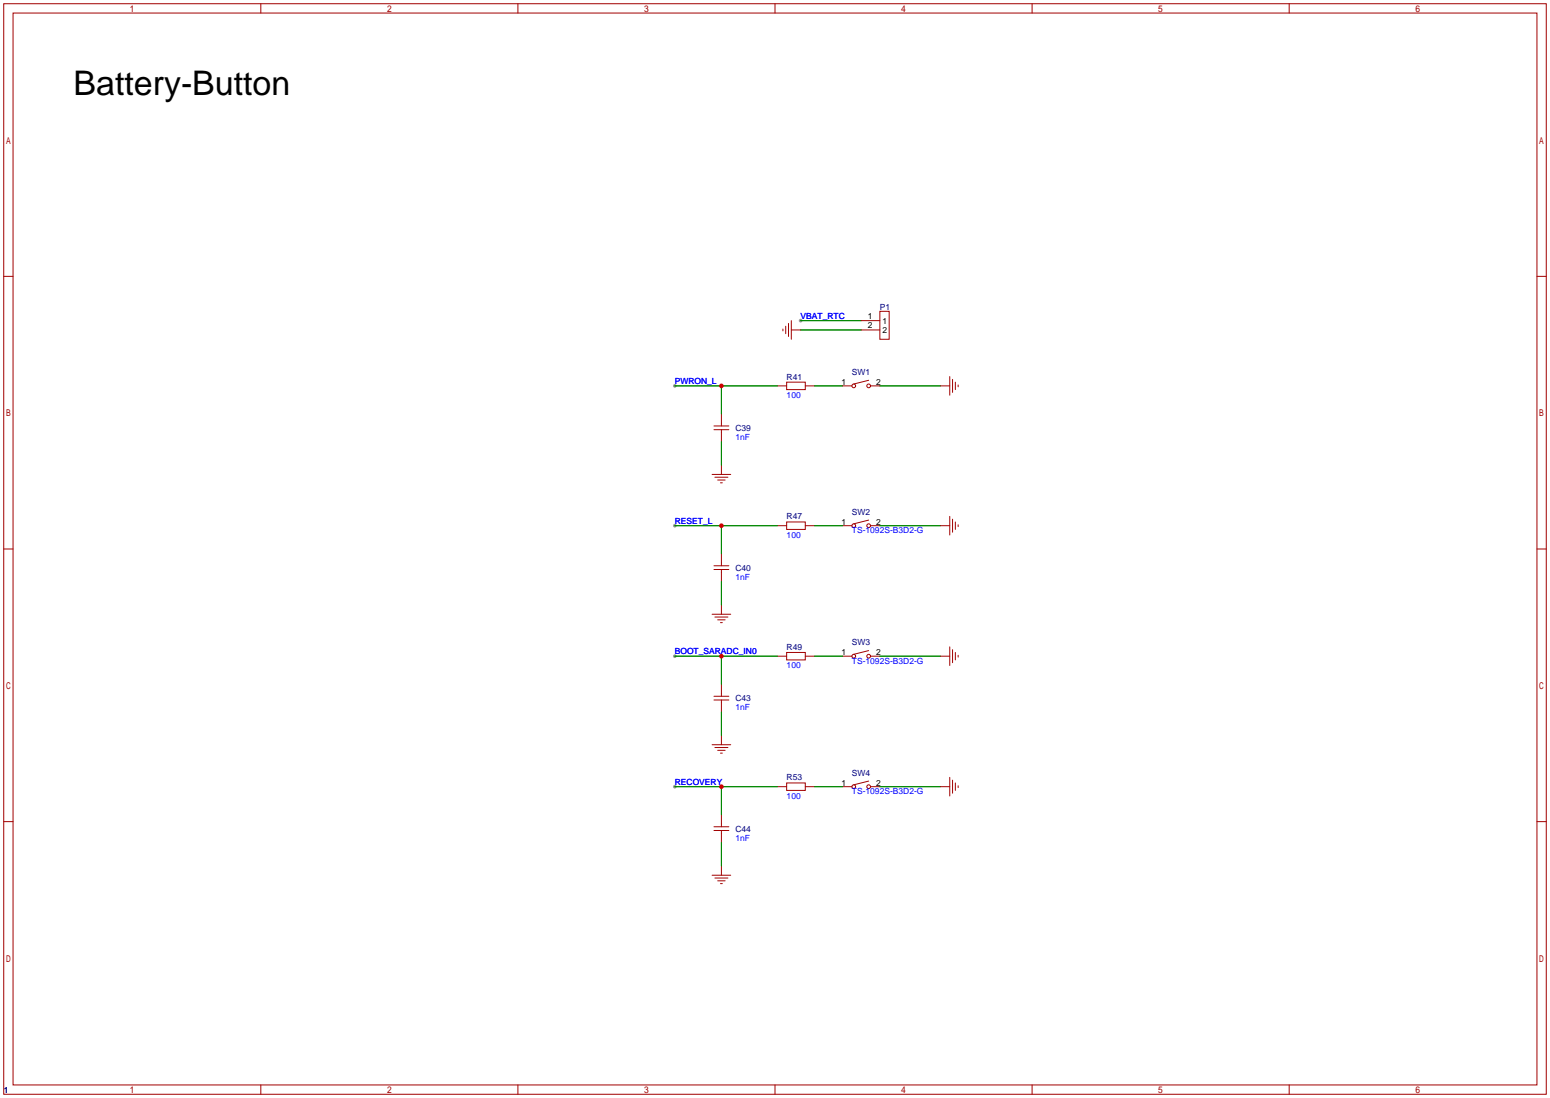
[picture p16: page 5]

# SDCARD

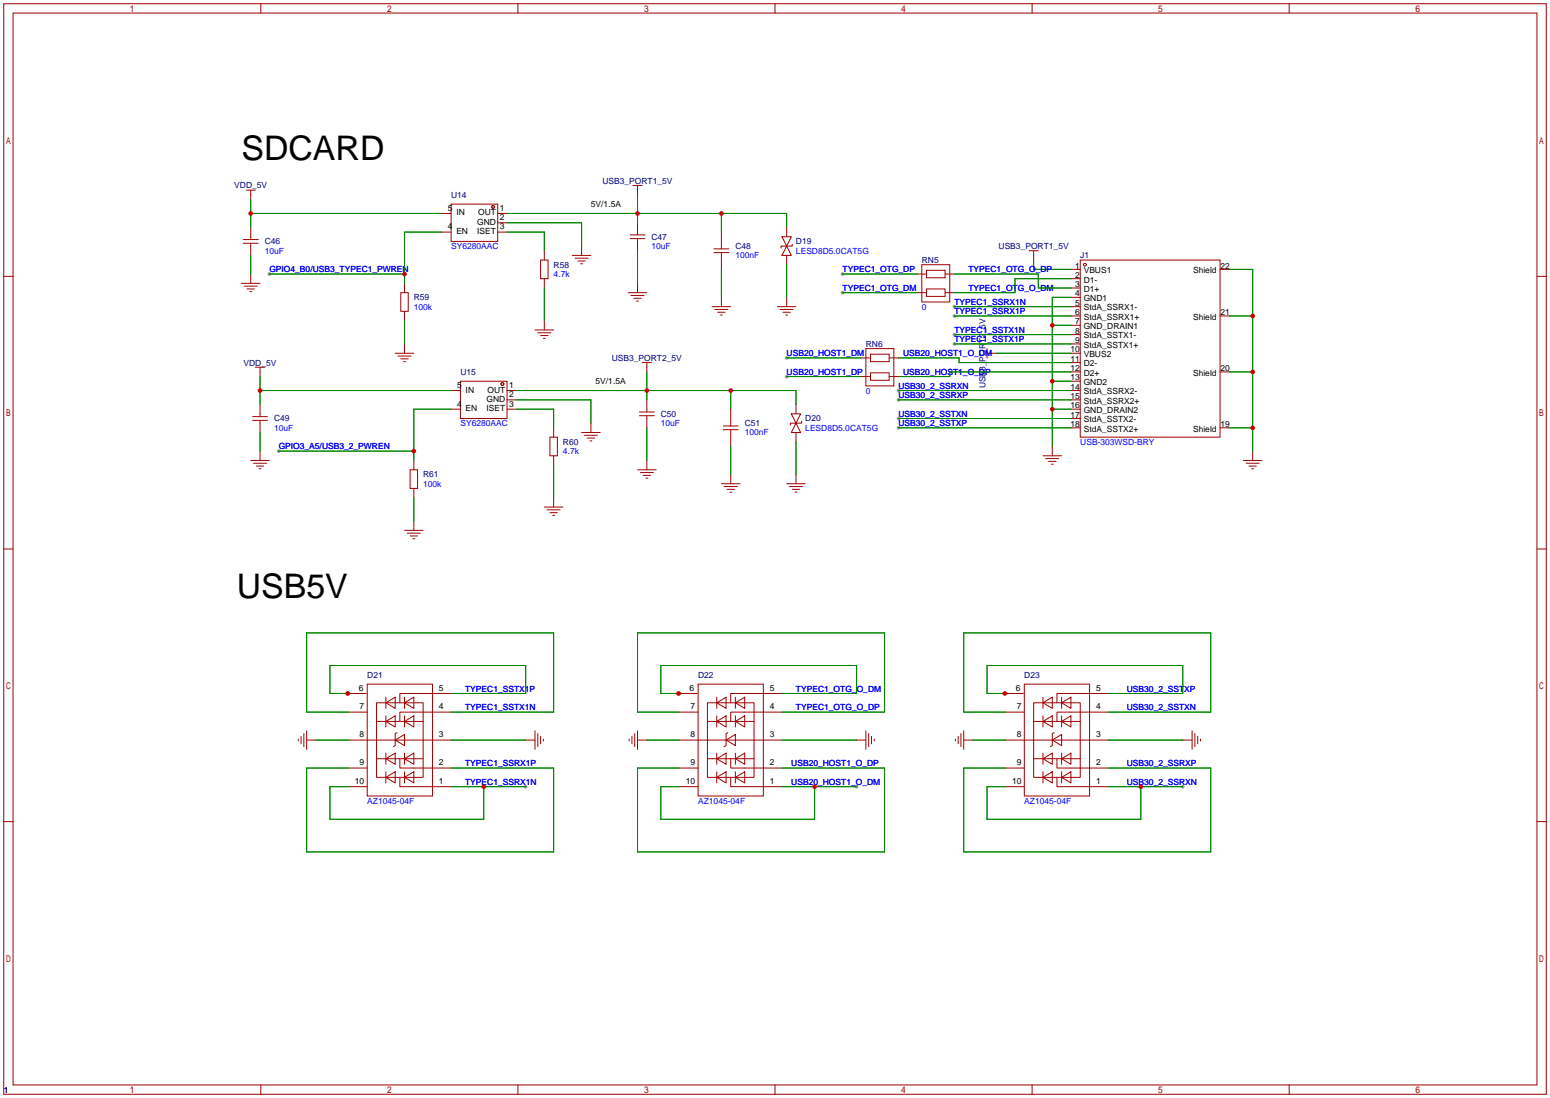
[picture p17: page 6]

# MicroSD

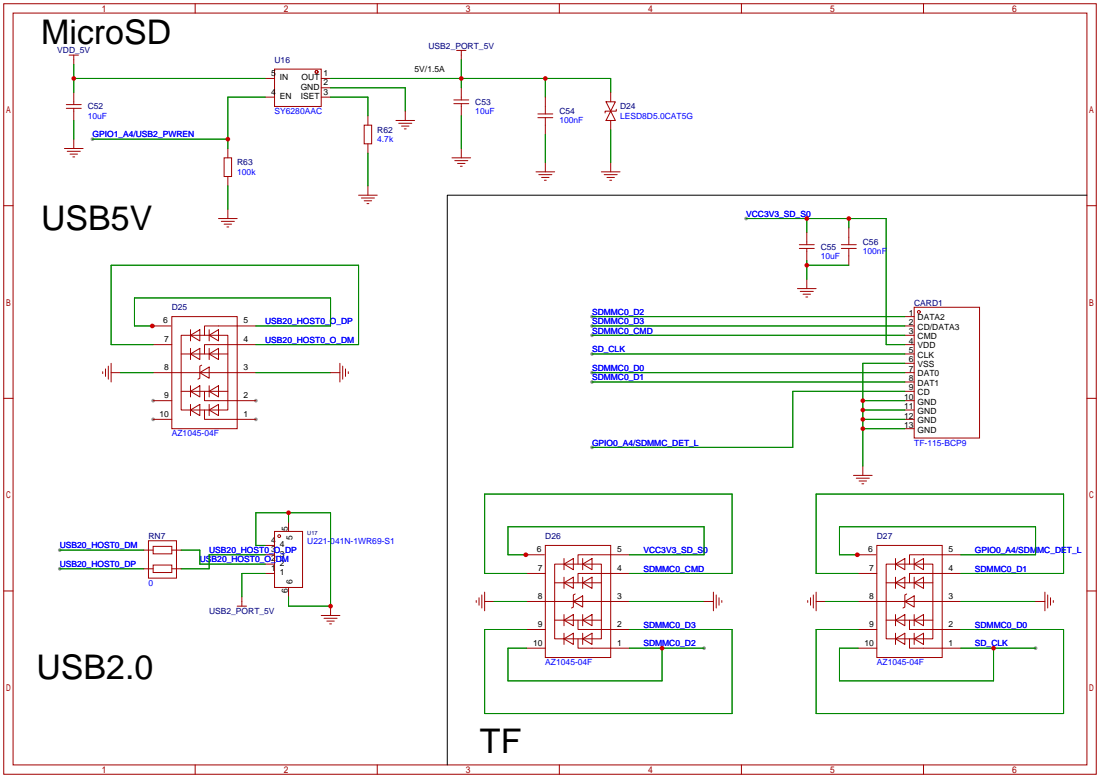
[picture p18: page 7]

# MIPI Camera (MIPI_CSI_RX 4lanes)

# Mipi CSI

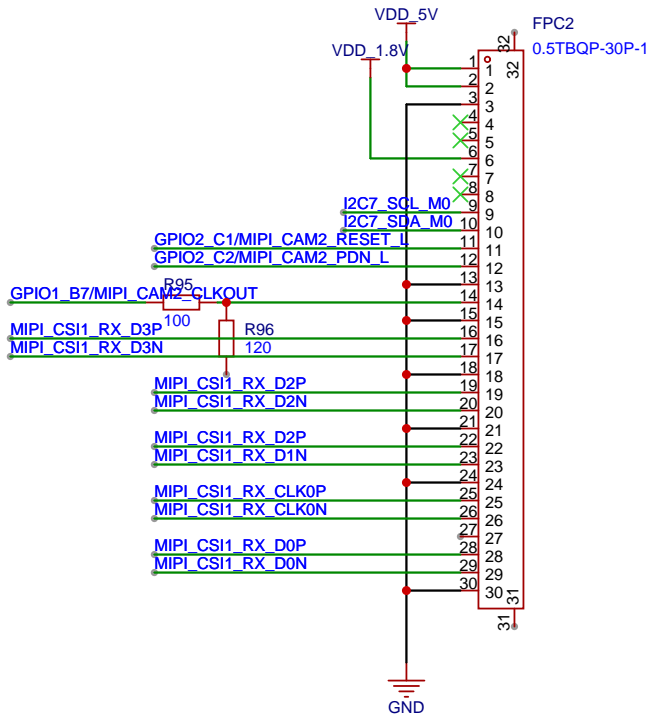
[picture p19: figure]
FPC2 0.5TBQP-30P-1; VDD_5V; GND; VDD_1.8V; I2C7_SCL_M0 I2C7_SDA_M0 GPIO2_C1/MIPI_CAM2_RESET_L GPIO2_C2/MIPI_CAM2_PDN_L R95; GPIO1_B7/MIPI_CAM2_CLKOUT; MIPI_CSI1_RX_D3P MIPI_CSI1_RX_D3N; MIPI_CSI1_RX_D2P MIPI_CSI1_RX_D2N; MIPI_CSI1_RX_D2P MIPI_CSI1_RX_D1N; MIPI_CSI1_RX_CLK0N; MIPI_CSI1_RX_CLK0P; MIPI_CSI1_RX_D0P MIPI_CSI1_RX_D0N

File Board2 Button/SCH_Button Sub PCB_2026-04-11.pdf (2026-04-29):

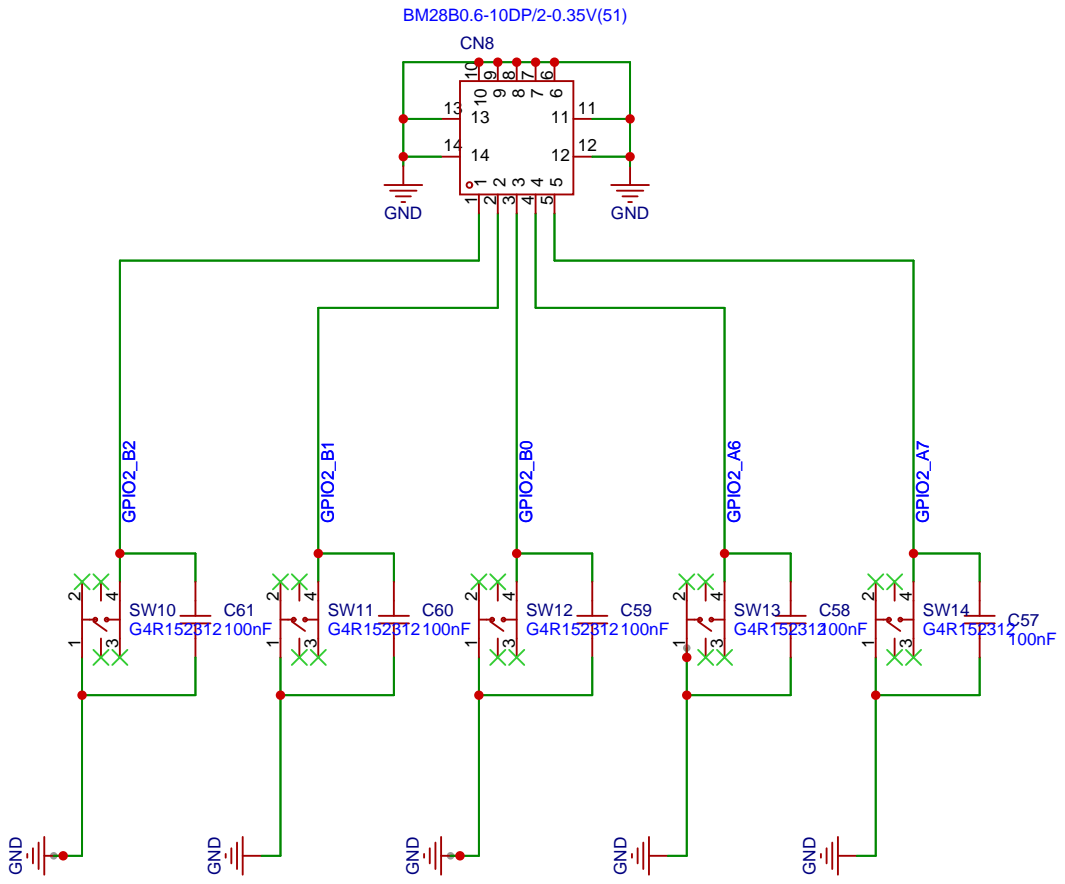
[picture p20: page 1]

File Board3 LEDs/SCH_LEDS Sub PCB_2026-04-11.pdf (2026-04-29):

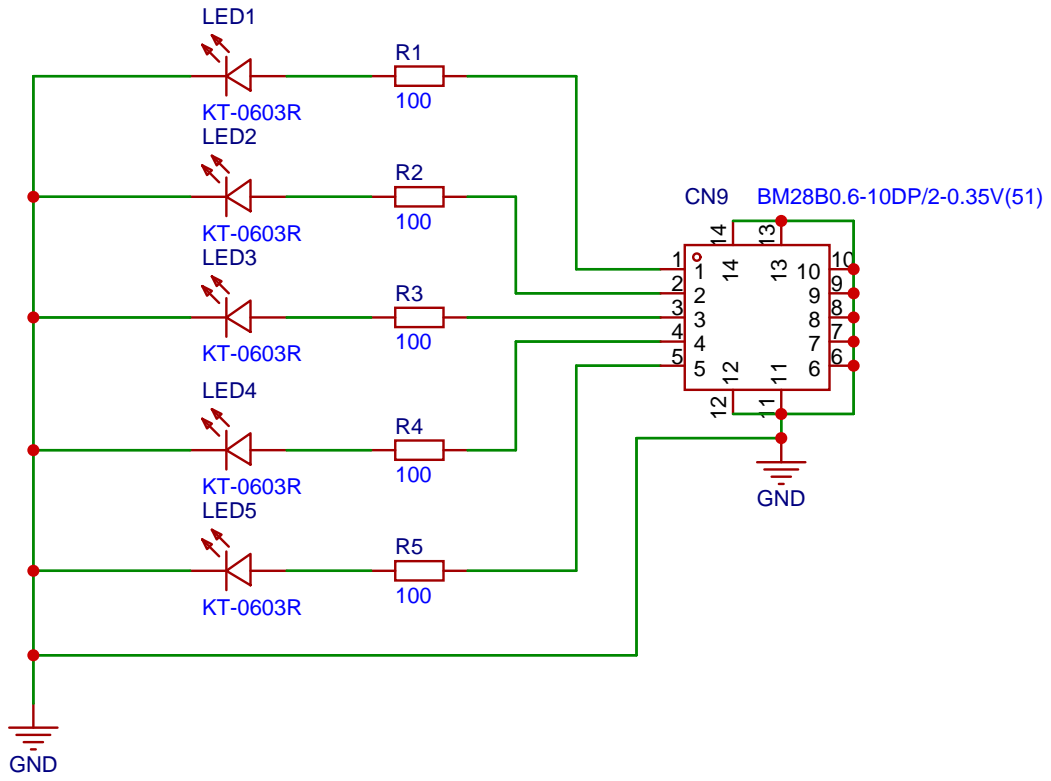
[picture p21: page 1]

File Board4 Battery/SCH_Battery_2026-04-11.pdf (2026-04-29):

DC | DC

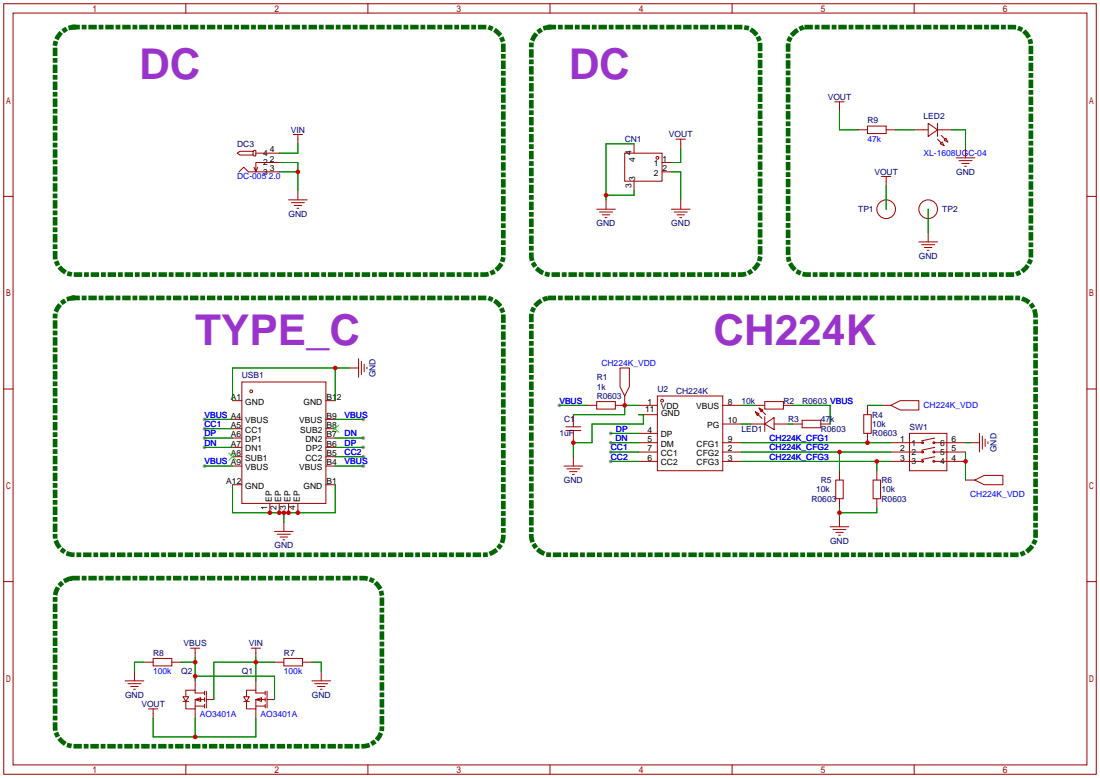
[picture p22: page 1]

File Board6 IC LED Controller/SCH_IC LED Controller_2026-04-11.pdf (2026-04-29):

# Ic Controller

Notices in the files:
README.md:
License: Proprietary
